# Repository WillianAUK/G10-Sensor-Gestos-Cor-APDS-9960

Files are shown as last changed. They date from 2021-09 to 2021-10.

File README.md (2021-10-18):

<p align="center">
  
  
  
  
  
  
  <a href="https://github.com/WillianAUK/G10-Sensor-Gestos-Cor-APDS-9960/commits/master">
    
  </a>
</p>

<h1 align="center">
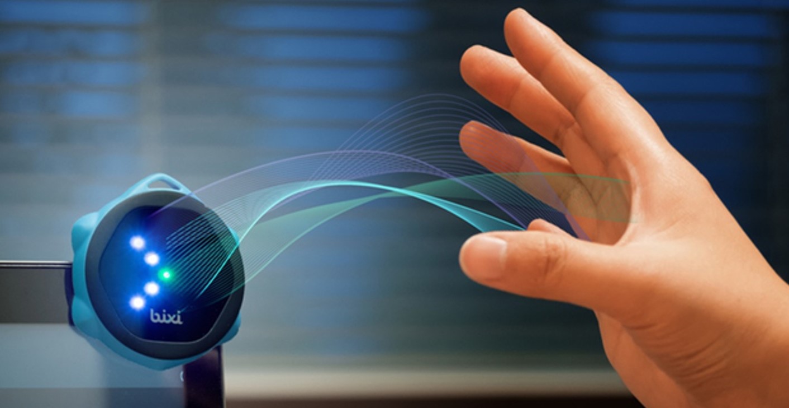
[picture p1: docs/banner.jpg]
Gcontrol #Gcontrol
    
</h1>

<h4 align="center"> 
	🚧  Gcontrol ⏯️ Em construção ⚠️ 🚧
</h4>

<p align="center">
 <a href="#-sobre-o-projeto">Sobre</a> •
 <a href="Setup">Setup</a> •
 <a href="Funcionalidades">Funcionalidades</a> •
 <a href="Contribuidores">Contribuidores</a> • 
 <a href="Licença">Licença</a>
</p>

## 💻 Sobre o projeto

⏯️ Gcontrol - é uma forma de acionar os controles de mídia por meio gestos identificados pelo sensor APDS-9960 

Projeto desenvolvido durante a disciplina de **Sistemas embarcados** ofertada pelo [IFPB - Campina Grande](https://www.ifpb.edu.br/campinagrande).
A disciplina faz parte do 9º semestre da grade currícular do curso de Engenharia de Computação do IFPB - Campina Grande e tem como responsável o professor [Dr. Alexandre Sales Vasconselos](http://lattes.cnpq.br/8740952344021265), que está ministrando-a no semestre 2021.1

Para videos demonstrativos e arquivos extras, acesse o o drive https://drive.google.com/drive/folders/1uk8sIaNC5tyi2TA3CVgvFQiCZkxG33-y?usp=sharing.

### Simulação

<table>
  <tr>
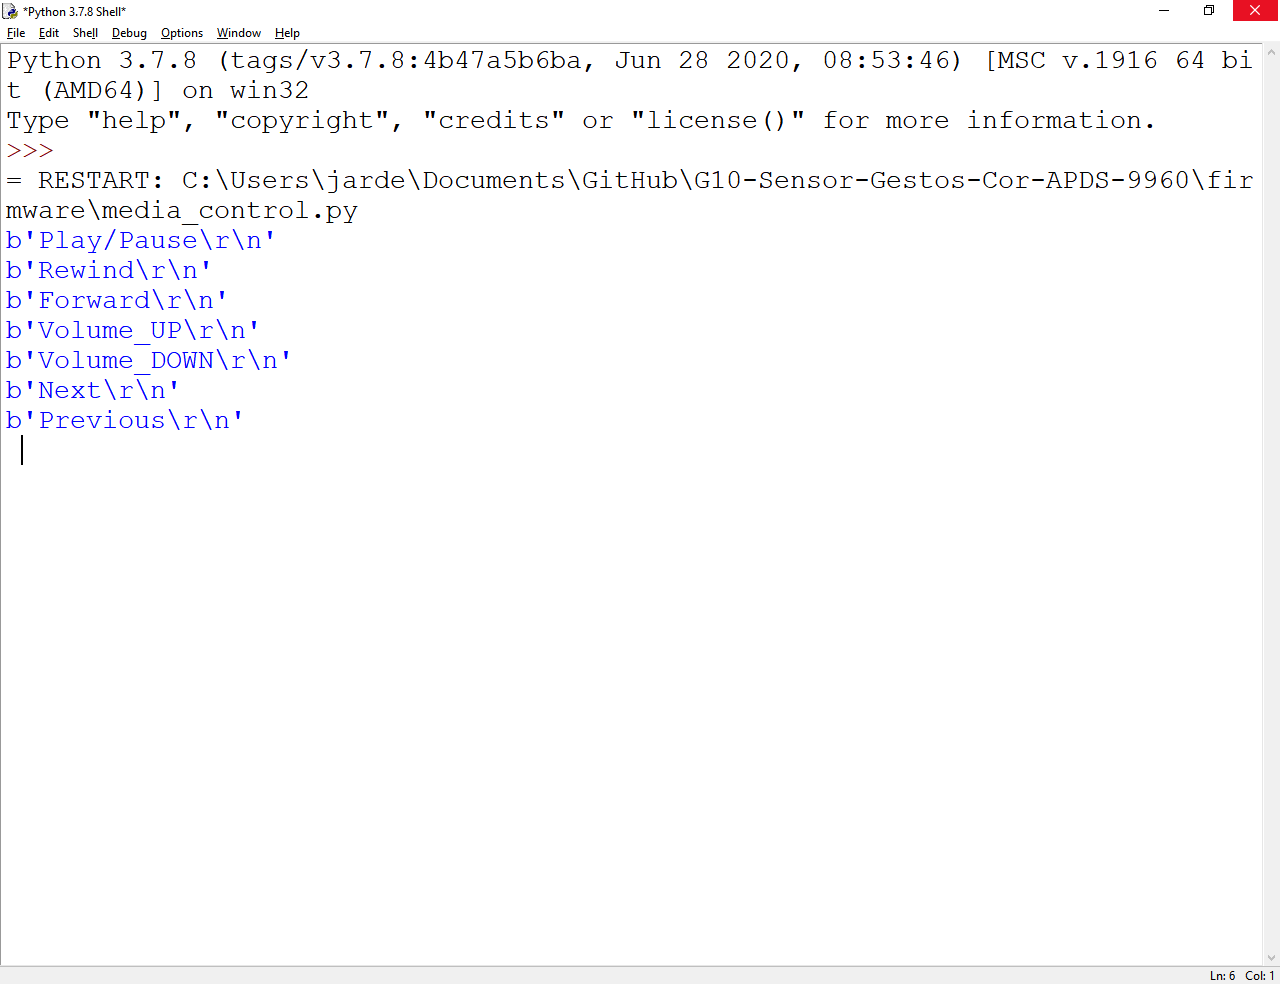
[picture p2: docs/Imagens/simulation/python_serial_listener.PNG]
    <td align="center"><br /><sub><b>Execução do script de comunicação Serial do S.O. com o arduino em Python </b></sub></a><br /> </td>
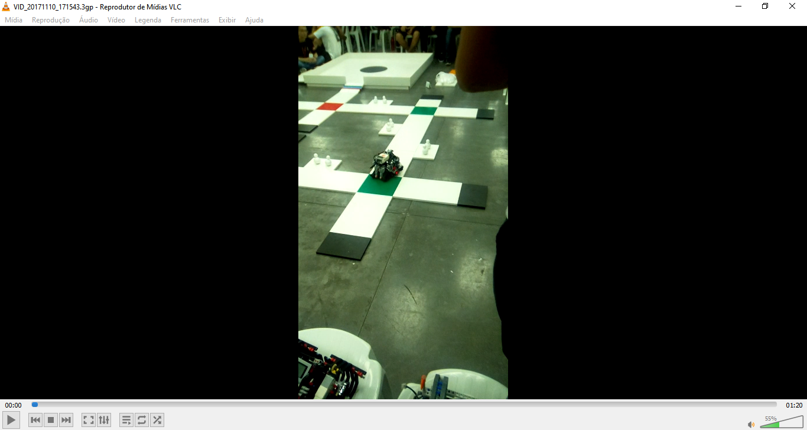
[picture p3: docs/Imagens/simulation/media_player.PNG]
    <td align="center"><br /><sub><b>Software de reprodução de mídia, utilizado como exemplo no projeto</b></sub></a><br /></td>
  </tr>
  <tr>
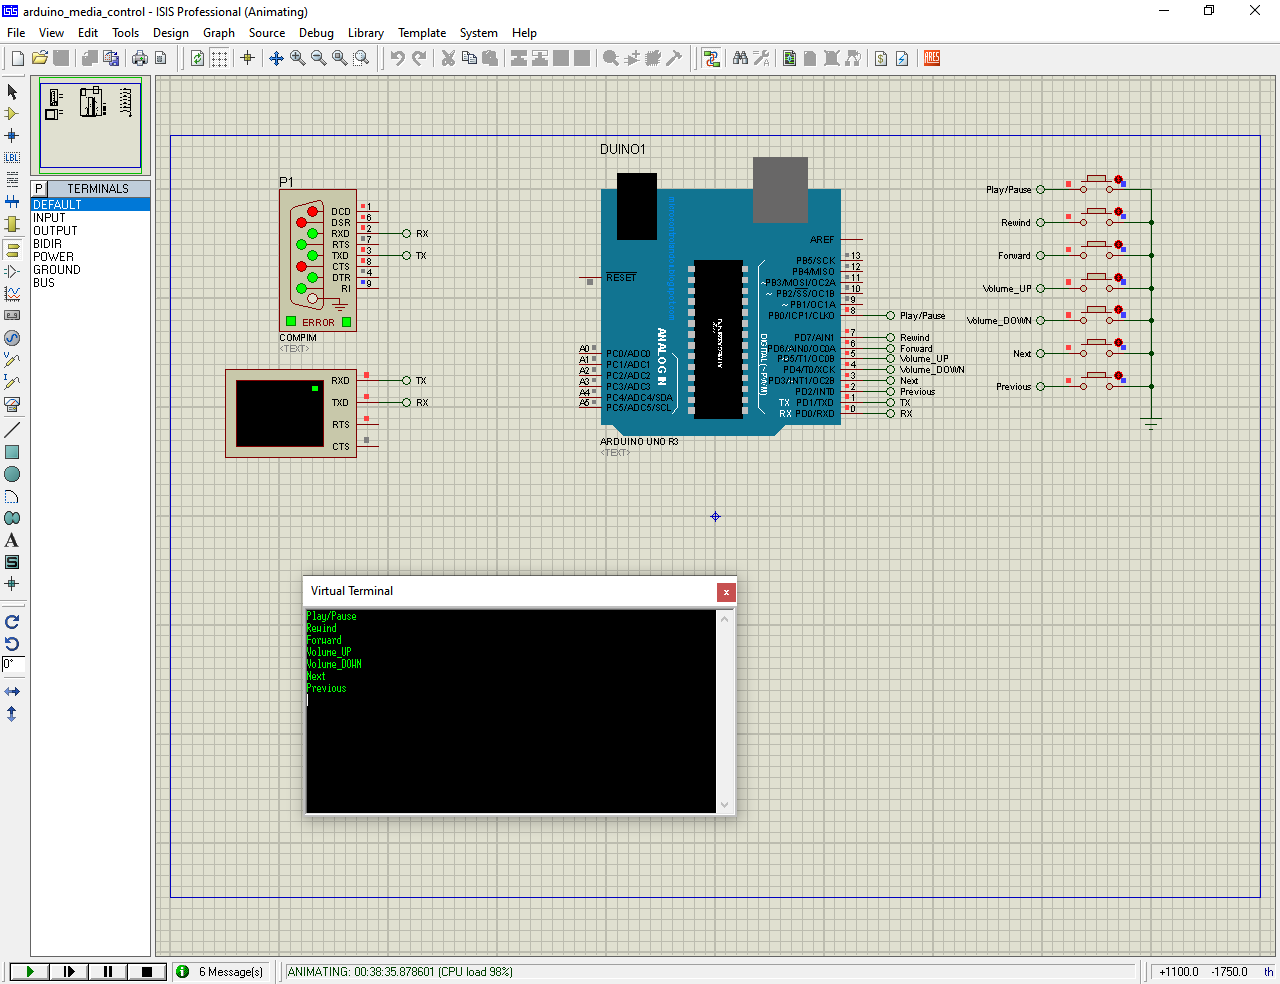
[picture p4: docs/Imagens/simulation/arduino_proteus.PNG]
     <td colspan="2" align="center"><br /><sub><b>Circuito simulado no proteus</b></sub></a><br /></a></td>
  </tr>
</table>

---

## ✔️ Setup

Para obter uma cópia local instalada e funcionando, siga estas etapas simples de exemplo.

### Pré requisitos

You need Python 3.5 or later to run mypy.  You can have multiple Python
versions (2.x and 3.x) installed on the same system without problems.

Você precisa do Python 3.5 ou posterior para executar o Gcontrol. Você pode ter várias versões do Python (2.xe 3.x) instaladas no mesmo sistema sem problemas.

No Ubuntu, Mint e Debian, você pode instalar o Python 3 assim:

    $ sudo apt-get install python3 python3-pip

Para outros tipos de Linux, macOS e Windows, os pacotes estão disponíveis em

  https://www.python.org/getit/

### Instalações

1. Atualize o pip do Python
   ```sh
   python -m pip install --upgrade pip --user
   ```
2. Instale o PySerial atráves do seguinte link ou comando [PySerial](https://pythonhosted.org/pyserial/pyserial.html#installation)
   ```sh
   python -m pip install pyserial
   ```
3. Instale o PyAutoGui atrábes do seguinte link ou comando [PyAutoGui](https://pyautogui.readthedocs.io/en/latest/install.html)
   ```sh
   python -m pip install pyautogui 
   ```
4. Rode o seguinte script Python [Gcontrol_listener](./firmware/media_control/media_control.py)
5. Rode o seguinte script Arduino, com as devidas adequações a sua implementação [Gcontrol_Arduino](./firmware/controller_media/controller_media.ino)
6. Fim

<p align="right">(<a href="#top">back to top</a>)</p>

## ⚙️ Funcionalidades

- [x] Conexão do hardwaare embarcado com software de reprodução de mídias
  - [x] Implementar os protocolos de comunicação
  
- [x] Os usuários tem acesso ao sistema integrado, onde podem por meio de gestos específicos:
  - [x] Pausar 
  - [x] Despausar
  - [x] Avançar
  - [x] Retroceder 
  - [x] Aumentar volume
  - [x] Diminuir volume

---

## 👨‍💻 Desenvolvedores

<table>
  <tr>
    <td align="center"><a href="https://github.com/WillianAUK"><br /><sub><b>Willian Adriano</b></sub></a><br /><a href="https://github.com/WillianAUK" title="Willian">👨‍🚀</a></td>
    <td align="center"><a href="https://github.com/JardelBrandon"><br /><sub><b>Jardel Brandon</b></sub></a><br /><a href="https://github.com/JardelBrandon" title="Jardel">👨‍🚀</a></td>
    <td align="center"><a href="https://github.com/kvalhomanu"><br /><sub><b>Marcelo Carvalho</b></sub></a><br /><a href="https://github.com/kvalhomanu" title="Marcelo">👨‍🚀</a></td>
  </tr>
</table>

## 💪 Como contribuir para o projeto

1. Faça um **fork** do projeto.
2. Crie uma nova branch com as suas alterações: `git checkout -b my-feature`
3. Salve as alterações e crie uma mensagem de commit contando o que você fez: `git commit -m "feature: My new feature"`
4. Envie as suas alterações: `git push origin my-feature`

---

## 📝 Licença

Este projeto esta sobe a licença [MIT](./LICENSE).

---

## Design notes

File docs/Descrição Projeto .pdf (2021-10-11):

| INSTITUTO FEDERAL DE EDUCAÇÃO, CIÊNCIA E TECNOLOGIA PARAÍBA CAMPUS CAMPINA GRANDE
PROFESSOR: ALEXANDRE SALES VASCONCELOS | DISCIPLINA: SISTEMAS EMBARCADOS
DATA: 11/10/2021 | ALUNOS: WILLIAN KLEIN, JARDEL REGIS, MANOEL CARVALHO

### Grupo 10 - Sensor de Gestos e Cor APDS-9960 com ESP-12E

Descrição do Projeto

Projeto desenvolvido durante a disciplina de Sistemas embarcados ofertada pelo IFPB - Campina Grande. A disciplina faz parte do 9º semestre da grade curricular do curso de Engenharia de Computação do IFPB - Campina Grande e tem como responsável o professor Dr. Alexandre Sales Vasconselos, que está ministrando-a no semestre 2021.1.
O projeto visa incorporar o Sensor de Gestos e Cor APDS-9960 junto ao microcontrolador ESP-12E, para que seja possível utilizar o sensor em protótipos ou produtos finais junto ao ESP-12E. Nesse repositório se encontram arquivos relacionados ao pcb protótipo de uma placa com ESP-12E um sensor APDS-9960, bibliotecas de software para que seja de fácil utilização, imagens e documentos como datasheet dos componentes utilizados.
Para facilitar o uso da comunidade, utilizamos a linguagem arduino.ino programando o ESP-12E diretamente pela Arduino IDE. Para saber como utilizar o ESP-12E na Arduino IDE, acesse aqui. (https://www.robocore.net/tutoriais/programando-o-esp8266-pela-arduino-ide)

Funcionalidades
- Proximidade:
Testa a detecção de proximidade do APDS-9960. Configura o APDS-9960 em I2C e pesquisa a distância para o objeto mais próximo do sensor.
- Controle de Gestos:
Testa a detecção de gestos do APDS-9960. Configura APDS-9960 sobre I2C e espera por eventos de gesto. Calcula a direção do movimento(para cima, para baixo, para a esquerda, para a direita) e exibe-o em um console serial.
- Sensor de Cor:
Testa as habilidades de detecção de cor e luz ambiente do APDS-9960. Configura APDS-9960 em I2C e consulta o sensor para luz ambiente e níveis de cor, que são exibidos sobre o console serial.

Lista de Componentes:

- 1 microcontrolador Esp-12E;
- 1 sensor APDS-9960;
- 4 capacitores de 10µF;

- 1 capacitor de 0.1µF;
- 9 resistores de 10kΩ;
- 1 resistor de 1kΩ;
- 2 diodos SOD-323;
- 2 diodos SOD-123;
- 1 led vermelho Nooutline;
- 2 Mosfets Nwide BSS138;
- 2 botões tact SMT4.6X2.8;
- 2 reguladores de voltagem SOT23-5;
- 1 Jumper HEADER-1X670MIL.

Imagens da placa

Esquemático:

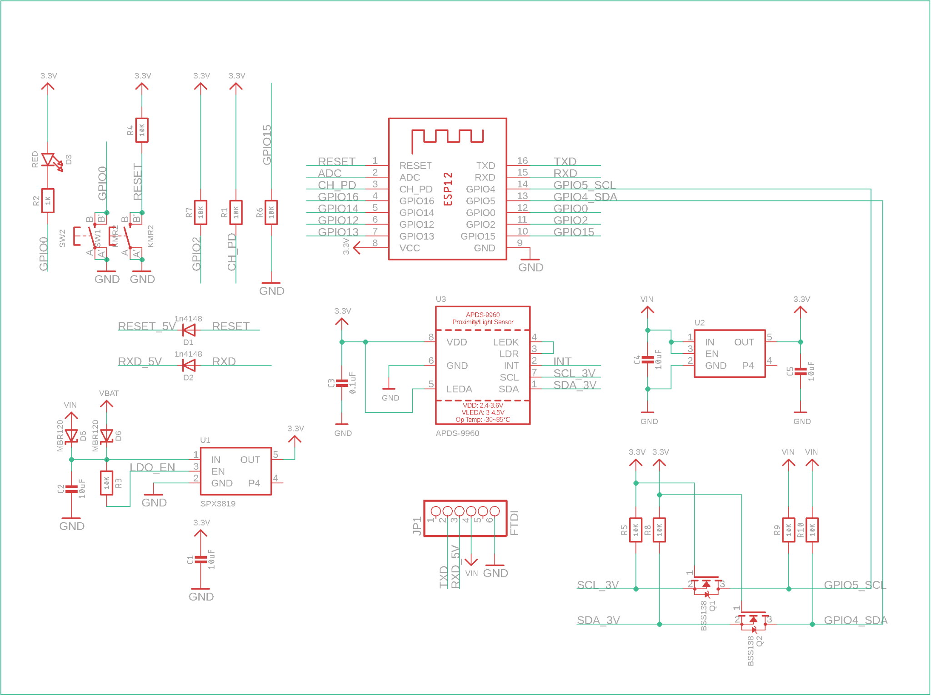
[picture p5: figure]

PCB:

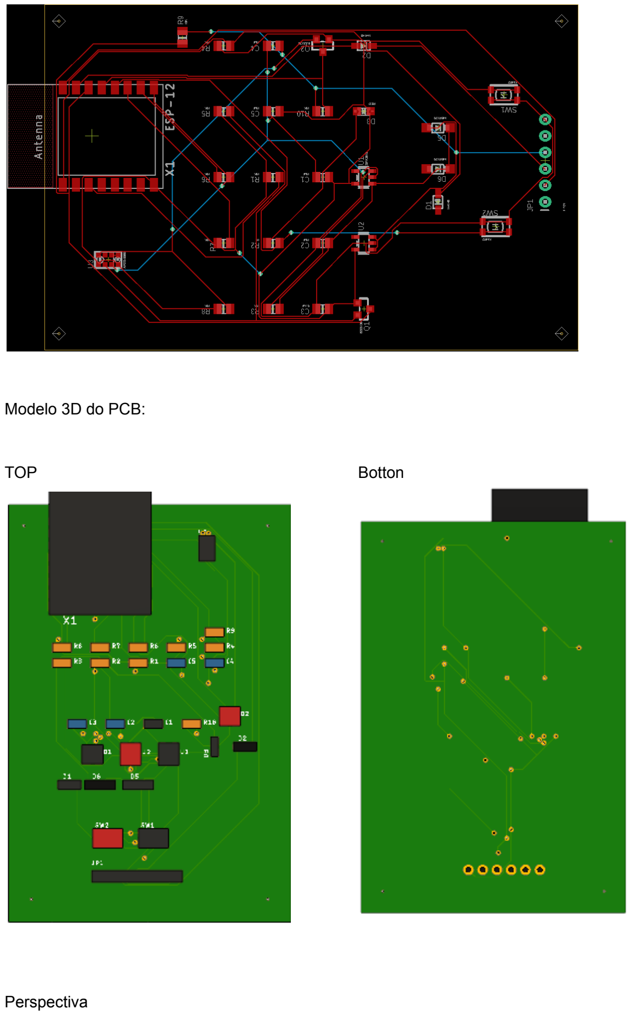
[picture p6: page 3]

Modelo 3D do PCB:

TOP | Botton

Perspectiva

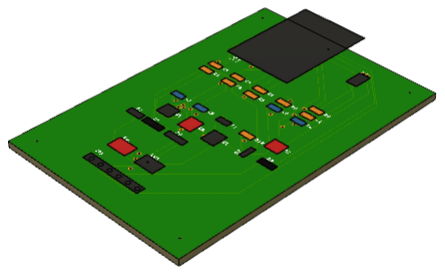
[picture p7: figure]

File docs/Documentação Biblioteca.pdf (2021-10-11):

| INSTITUTO FEDERAL DE EDUCAÇÃO, CIÊNCIA E TECNOLOGIA PARAÍBA CAMPUS CAMPINA GRANDE
PROFESSOR: ALEXANDRE SALES VASCONCELOS | DISCIPLINA: SISTEMAS EMBARCADOS
DATA: 11/10/2021 | ALUNOS: WILLIAN KLEIN, JARDEL REGIS, MANOEL CARVALHO

### Grupo 10 - Sensor de Gestos e Cor APDS-9960 com ESP-12E

Documentação biblioteca

Descrição: A biblioteca APDS9960.h é responsável pela comunicação entre o microcontrolador ESP-12E com o sensor de Gestos e Cor APDS-9960 e pelos métodos de leitura gestos, de cores, proximidade e luz ambiente. A biblioteca foi feita utilizando a linguagem arduino, porém utilizada no ESP-12E através de extensões da IDE. Para saber como utilizar a familia esp na Arduino IDE, acesse aqui. (https://www.robocore.net/tutoriais/programando-o-esp8266-pela-arduino-ide)

Importação: Para importar a biblioteca basta fazer o | #include | do arquivo APDS9960.h .

#include <APDS9960.h>

Funções:
Seguem as funções presentes.
- Gerais:
- apds.init(): Inicia a biblioteca e configura os valores iniciais de I2C.
- Proximidade:
Testa a detecção de proximidade do APDS-9960. Configura o APDS-9960 em I2C e pesquisa a distância para o objeto mais próximo do sensor.
- !apds.setProximityGain(PGAIN_2X): Ajuste o ganho do sensor de
proximidade
- apds.enableProximitySensor(false) : Começa a executar o sensor de
proximidade APDS-9960 sem interrupções.
- !apds.readProximity(proximity_data) : Faz a leitura dos valores de
proximidade e retorna o valor.
- Controle de Gestos:
Testa a detecção de gestos do APDS-9960. Configura APDS-9960 sobre I2C e espera por eventos de gesto. Calcula a direção do movimento(para cima, para baixo, para a esquerda, para a direita) e exibe-o em um console serial.
- apds.enableGestureSensor(true): Comece a executar o modulo do
sensor de gestos APDS-9960.

- apds.isGestureAvailable() : Verifica se o módulo de controle de gestos está ativo.
- apds.readGesture() : Retorna de acordo ao gesto DIR_UP, DIR_DOWN, DIR_LEFT, DIR_RIGHT, DIR_NEAR, DIR_FAR ou None.
- Sensor de Cor:
Testa as habilidades de detecção de cor e luz ambiente do APDS-9960. Configura APDS-9960 em I2C e consulta o sensor para luz ambiente e níveis de cor, que são exibidos sobre o console serial.
- apds.enableLightSensor(false): Comece a executar o sensor de luz APDS-9960.
- !apds.readAmbientLight(ambient_light) : Faz a leitura do nível de luz
no ambiente.
- !apds.readRedLight(red_light) : Faz a leitura do nível luz vermelha do ambiente.
- !apds.readGreenLight(green_light) : Faz a leitura do nível de luz verde
do ambiente.
- !apds.readBlueLight(blue_light) : Faz a leitura do nível de luz azul do ambiente.

Exemplos:
Nesse repositório existem exemplos de aplicação das funções presentes na biblioteca. Os exemplos fazem a aplicação das funções e mostram no monitor serial da IDE arduino.

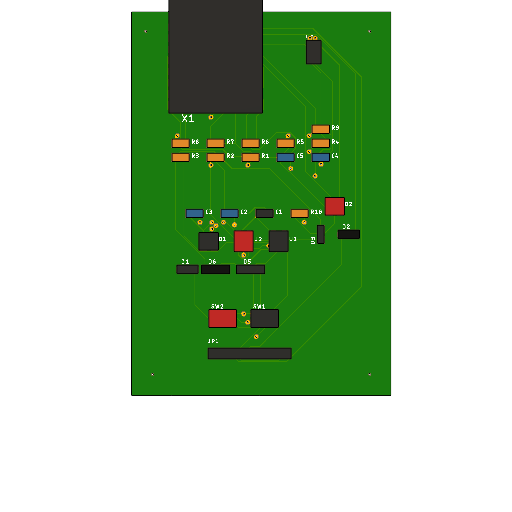
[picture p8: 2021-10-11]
docs/Imagens/3D-top.png

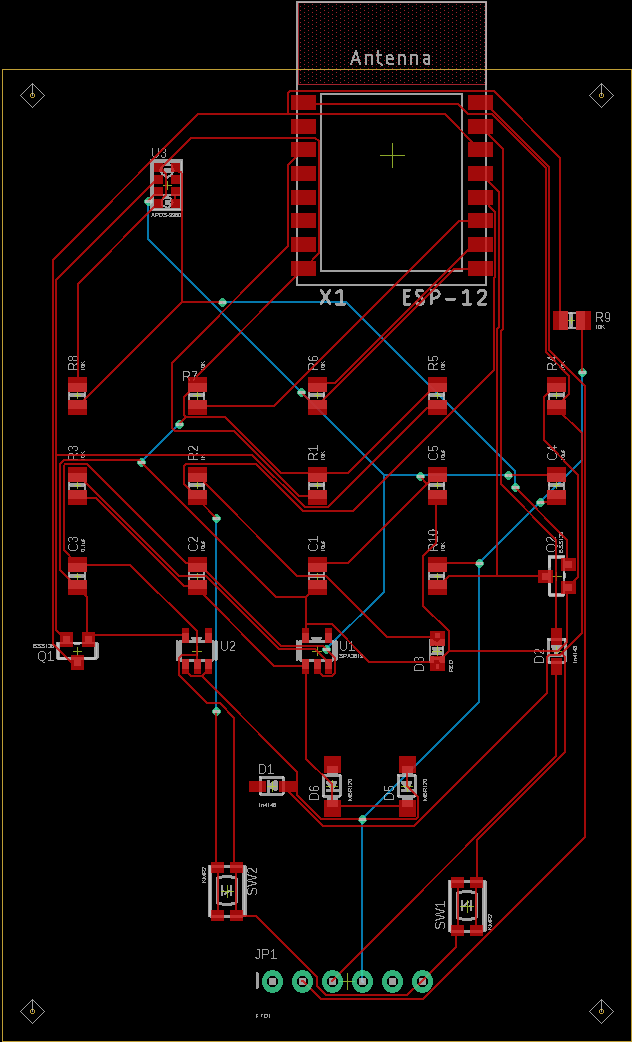
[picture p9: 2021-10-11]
docs/Imagens/PCB.png

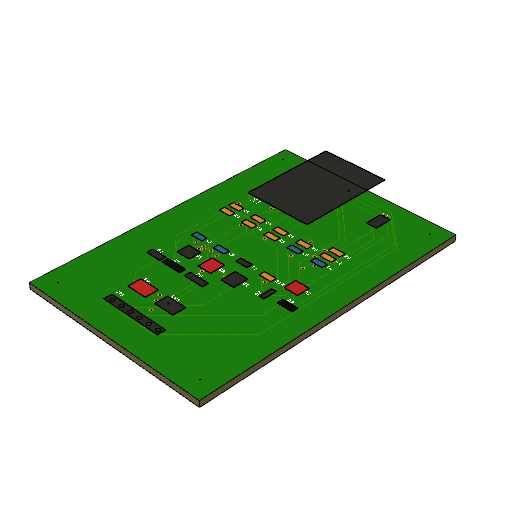
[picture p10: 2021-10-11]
docs/Imagens/3d-perspective.png

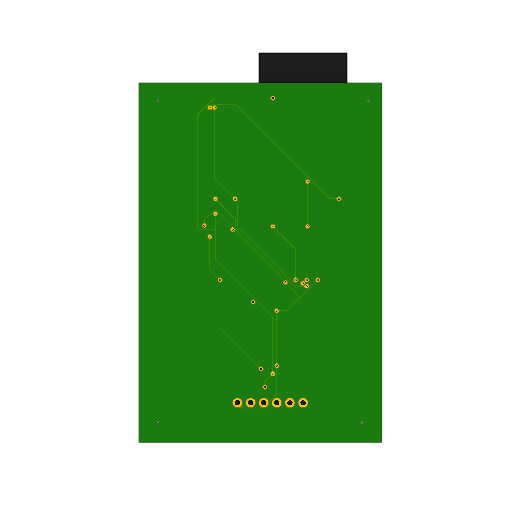
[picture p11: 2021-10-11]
docs/Imagens/3D-botton.png

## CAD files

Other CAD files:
pcb/projeto - modelo 3D gerado v0.1.f3d

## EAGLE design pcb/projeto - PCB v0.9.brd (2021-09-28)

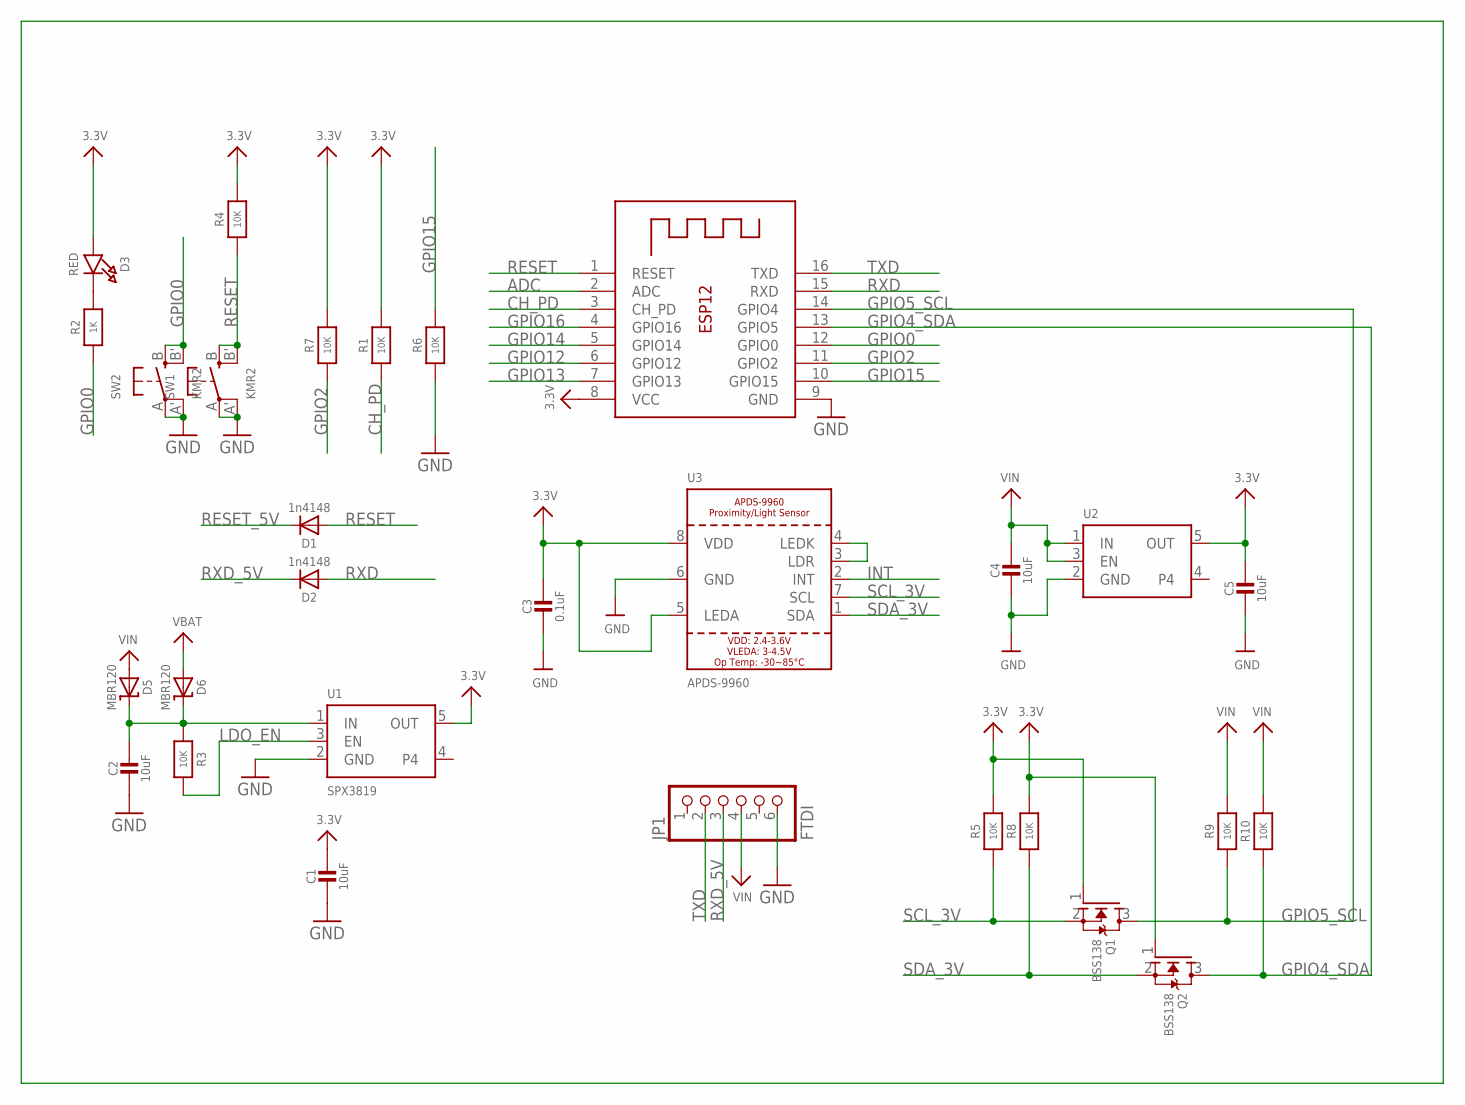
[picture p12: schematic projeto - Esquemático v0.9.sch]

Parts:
C1, C2, C4, C5: 10uF; 0805-NO
C3: 0.1uF; 0805-NO
D1, D2: 1n4148; SOD-323
D3: RED; CHIPLED_0805_NOOUTLINE
D5, D6: MBR120; SOD-123
JP1: FTDI; 1X06_ROUND_70
Q1, Q2: BSS138; SOT23-WIDE
R1, R3, R4, R5, R6, R7, R8, R9, R10: 10K; 0805-NO
R2: 1K; 0805-NO
SW1, SW2: KMR2; BTN_KMR2_4.6X2.8
U1: SPX3819; SOT23-5
U2: VREG_SOT23-5; SOT23-5
U3: APDS-9960
X1: ESP-12

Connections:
3.3V: C1.1, C3.1, C5.1, D3.A, Q1.1 (G), Q2.1 (G), R1.2, R4.2, R5.2, R7.2, R8.2, U1.5 (OUT), U2.5 (OUT), U3.5 (LEDA), U3.8 (VDD), X1.8 (VCC)
ADC: X1.2 (ADC)
CH_PD: R1.1, X1.3 (CH_PD)
GND: C1.2, C2.2, C3.2, C4.2, C5.2, JP1.6, R6.1, SW1.A, SW1.A' (P1), SW2.A, SW2.A' (P1), U1.2 (GND), U2.2 (GND), U3.6 (GND), X1.9 (GND)
GPIO0: R2.1, SW2.B (S), SW2.B' (S1), X1.12 (GPIO0)
GPIO2: R7.1, X1.11 (GPIO2)
GPIO4_SDA: Q2.3 (D), R10.1, X1.13 (GPIO5)
GPIO5_SCL: Q1.3 (D), R9.1, X1.14 (GPIO4)
GPIO12: X1.6 (GPIO12)
GPIO13: X1.7 (GPIO13)
GPIO14: X1.5 (GPIO14)
GPIO15: R6.2, X1.10 (GPIO15)
GPIO16: X1.4 (GPIO16)
INT: U3.2 (INT)
LDO_EN: R3.2, U1.3 (EN)
unnamed: C2.1, D5.C, D6.C, R3.1, U1.1 (IN)
unnamed: U3.3 (LDR), U3.4 (LEDK)
unnamed: D3.C, R2.2
RESET: D1.A, R4.1, SW1.B (S), SW1.B' (S1), X1.1 (RESET)
RESET_5V: D1.C
RXD: D2.A, X1.15 (RXD)
RXD_5V: D2.C, JP1.3
SCL_3V: Q1.2 (S), R5.1, U3.7 (SCL)
SDA_3V: Q2.2 (S), R8.1, U3.1 (SDA)
TXD: JP1.2, X1.16 (TXD)
VBAT: D6.A
VIN: C4.1, D5.A, JP1.4, R9.2, R10.2, U2.1 (IN), U2.3 (EN)

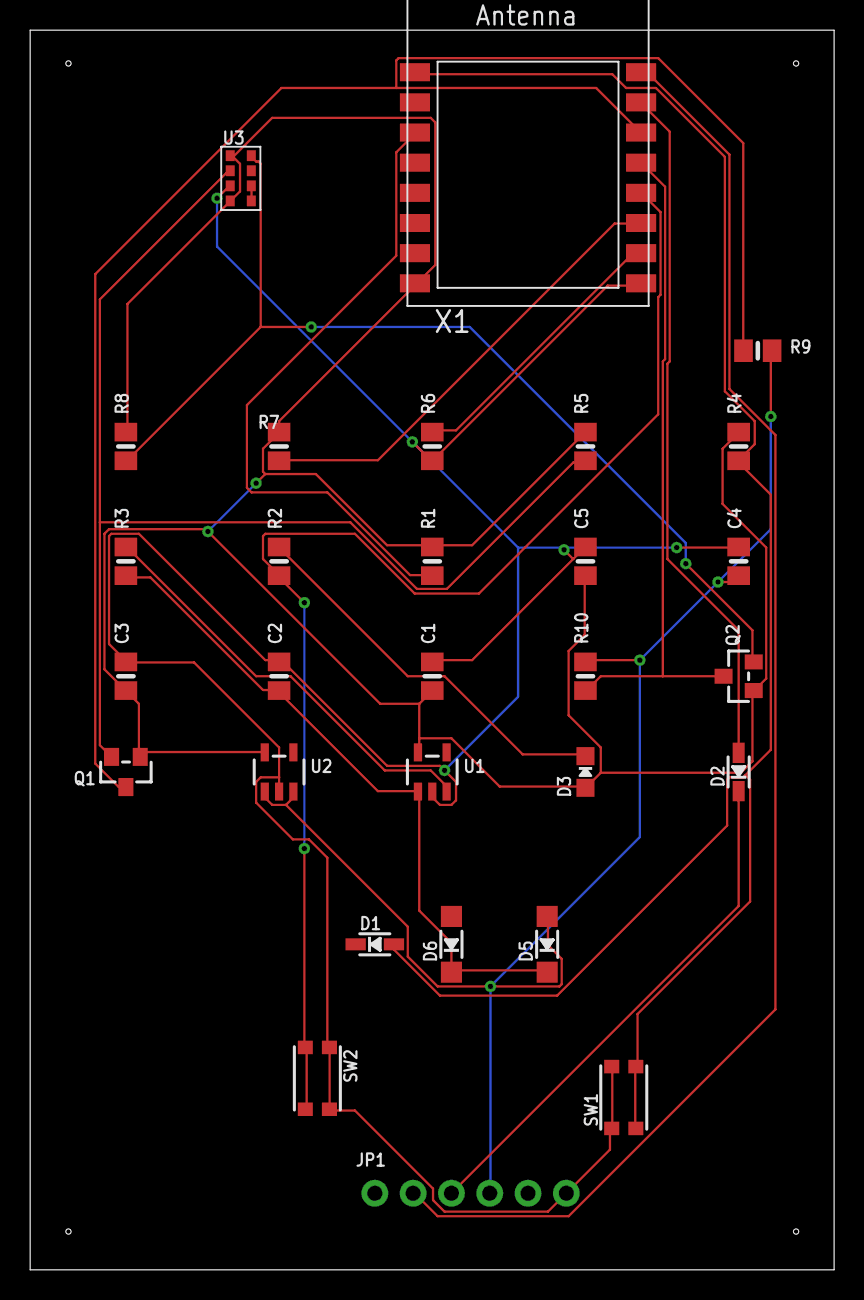
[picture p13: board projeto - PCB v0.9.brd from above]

Board: 2 copper layers, 53.3 x 82.2 mm, 29 parts (0 on the bottom side), 19 nets.

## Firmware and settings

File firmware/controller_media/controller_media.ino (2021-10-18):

const int BUTTON_PLAY_PAUSE = 8;
const int BUTTON_REWIND = 7;
const int BUTTON_FORWARD = 6;
const int BUTTON_VOLUME_UP = 5;
const int BUTTON_VOLUME_DOWN= 4;
const int BUTTON_NEXT = 3;
const int BUTTON_PREVIOUS = 2;

bool statePlayPause;
bool stateRewind;
bool stateForward;
bool stateVolumeUp;
bool stateVolumeDown;
bool stateNext;
bool statePrevious;

bool previousStatePlayPause;
bool previousStateRewind;
bool previousStateForward;
bool previousStateVolumeUp;
bool previousStateVolumeDown;
bool previousStateNext;
bool previousStatePrevious;

void setup() {
  Serial.begin(9600);
  
  pinMode(BUTTON_PLAY_PAUSE, INPUT_PULLUP);
  pinMode(BUTTON_REWIND, INPUT_PULLUP);
  pinMode(BUTTON_FORWARD, INPUT_PULLUP);
  pinMode(BUTTON_VOLUME_UP, INPUT_PULLUP);
  pinMode(BUTTON_VOLUME_DOWN, INPUT_PULLUP);
  pinMode(BUTTON_NEXT, INPUT_PULLUP);
  pinMode(BUTTON_PREVIOUS, INPUT_PULLUP);

  previousStatePlayPause = !digitalRead(BUTTON_PLAY_PAUSE);
  previousStateRewind = !digitalRead(BUTTON_REWIND);
  previousStateForward = !digitalRead(BUTTON_FORWARD);
  previousStateVolumeUp = !digitalRead(BUTTON_VOLUME_UP);
  previousStateVolumeDown = !digitalRead(BUTTON_VOLUME_DOWN);
  previousStateNext = !digitalRead(BUTTON_NEXT);
  previousStatePrevious = !digitalRead(BUTTON_PREVIOUS);
}

void loop() {
  statePlayPause = !digitalRead(BUTTON_PLAY_PAUSE);
  stateRewind = !digitalRead(BUTTON_REWIND);
  stateForward = !digitalRead(BUTTON_FORWARD);
  stateVolumeUp = !digitalRead(BUTTON_VOLUME_UP);
  stateVolumeDown = !digitalRead(BUTTON_VOLUME_DOWN);
  stateNext = !digitalRead(BUTTON_NEXT);
  statePrevious = !digitalRead(BUTTON_PREVIOUS);
  
  if (statePlayPause != previousStatePlayPause) {
    if (statePlayPause) {
      Serial.println("Play/Pause");
    }
  }
  if (stateRewind != previousStateRewind) {
    if (stateRewind) {
      Serial.println("Rewind");
    }
  }
  if (stateForward != previousStateForward) {
    if (stateForward) {
      Serial.println("Forward");
    }
  }
  if (stateVolumeUp != previousStateVolumeUp) {
    if (stateVolumeUp) {
      Serial.println("Volume_UP");
    }
  }
  if (stateVolumeDown != previousStateVolumeDown) {
    if (stateVolumeDown) {
      Serial.println("Volume_DOWN");
    }
  }
  if (stateNext != previousStateNext) {
    if (stateNext) {
      Serial.println("Next");
    }
  }
   if (statePrevious != previousStatePrevious) {
    if (statePrevious) {
      Serial.println("Previous");
    }
  }
  
  previousStatePlayPause = statePlayPause;
  previousStateRewind = stateRewind;
  previousStateForward = stateForward;
  previousStateVolumeUp = stateVolumeUp;
  previousStateVolumeDown = stateVolumeDown;
  previousStateNext = stateNext;
  previousStatePrevious = statePrevious;
  
  delay(50); //debounce
}

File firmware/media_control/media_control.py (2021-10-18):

import serial #Serial imported for Serial communication
import time #Required to use delay functions
import pyautogui

ArduinoSerial = serial.Serial('com1',9600) #Create Serial port object called arduinoSerialData
time.sleep(2) #wait for 2 seconds for the communication to get established

while True:
    incoming = str (ArduinoSerial.readline()) #read the serial data and print it as line
    print (incoming)

    if 'Play/Pause' in incoming:
        pyautogui.hotkey('alt', 'tab', interval=0.1)
        pyautogui.typewrite(['space'], 0.2)

    if 'Rewind' in incoming:
        pyautogui.hotkey('alt', 'tab', interval=0.1)
        pyautogui.hotkey('ctrl', 'left', interval=0.2)  

    if 'Forward' in incoming:
        pyautogui.hotkey('alt', 'tab', interval=0.1)
        pyautogui.hotkey('ctrl', 'right', interval=0.2)   

    if 'Volume_UP' in incoming:
        pyautogui.hotkey('alt', 'tab', interval=0.1)
        pyautogui.hotkey('ctrl', 'up', interval=0.2)  
        
    if 'Volume_DOWN' in incoming:
        pyautogui.hotkey('alt', 'tab', interval=0.1)
        pyautogui.hotkey('ctrl', 'down', interval=0.2)  

    if 'Next' in incoming:
        pyautogui.hotkey('alt', 'tab', interval=0.1)
        pyautogui.hotkey('n', interval=.2)

    if 'Previous' in incoming:
        pyautogui.hotkey('alt', 'tab', interval=0.1)
        pyautogui.hotkey('p', interval=0.2)  

    incoming = "";

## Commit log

2021-08-09 Adicionando licença
    Criando arquivo com as regras de licença de uso do sistema
2021-09-28 adicinando arquivos esquematico, PCB e 3D
    [projeto - Esquemático v0.9.sch, projeto - PCB v0.9.brd, projeto - modelo 3D gerado v0.1.f3d]
2021-10-17 Imagens
    Adicionando imagens de simulação do projeto
2021-10-17 Programa para o arduino
    Adicionando arquivo de programação do arduino
2021-10-17 Programa python para Interface Arduino - S.O
    Adicionando script em python que realiza a interface comunicação do S.O com o arduino para controle do media player
2021-10-17 Simulação Proteus
    Adicionando arquivos do circuito simulado no proteus, a simulição manda os dados via interface Serial para o script em python que realiza as respectivas funcionalidades no software alvo
    [arduino_media_control.DSN]
2021-10-18 Vídeo demonstrativo
    Adicionando vídeo de demonstração do projeto em funcionamento
2021-10-18 Setup
    Adicionando um tópico de getting started, com as instruções necessárias para o setup inicial de configuração e instalações das dependências do projeto, para execução bem sucedida do projeto

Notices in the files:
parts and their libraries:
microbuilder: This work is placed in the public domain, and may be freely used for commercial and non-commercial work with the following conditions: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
